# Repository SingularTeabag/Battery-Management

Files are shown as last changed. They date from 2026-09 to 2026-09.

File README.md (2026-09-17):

# **Battery-Management**
A repository to organize my battery management PCBs

## Single Cell 5 Volt Regulator
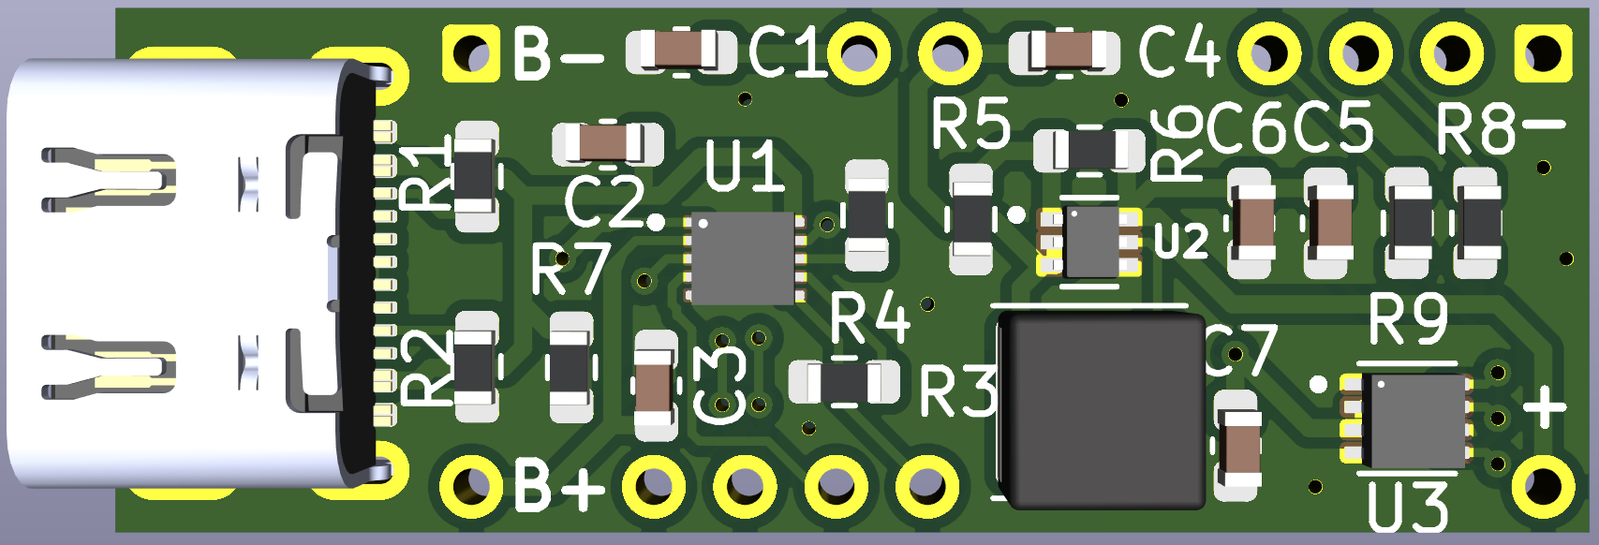
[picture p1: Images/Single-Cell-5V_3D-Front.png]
3D Front PCB Image

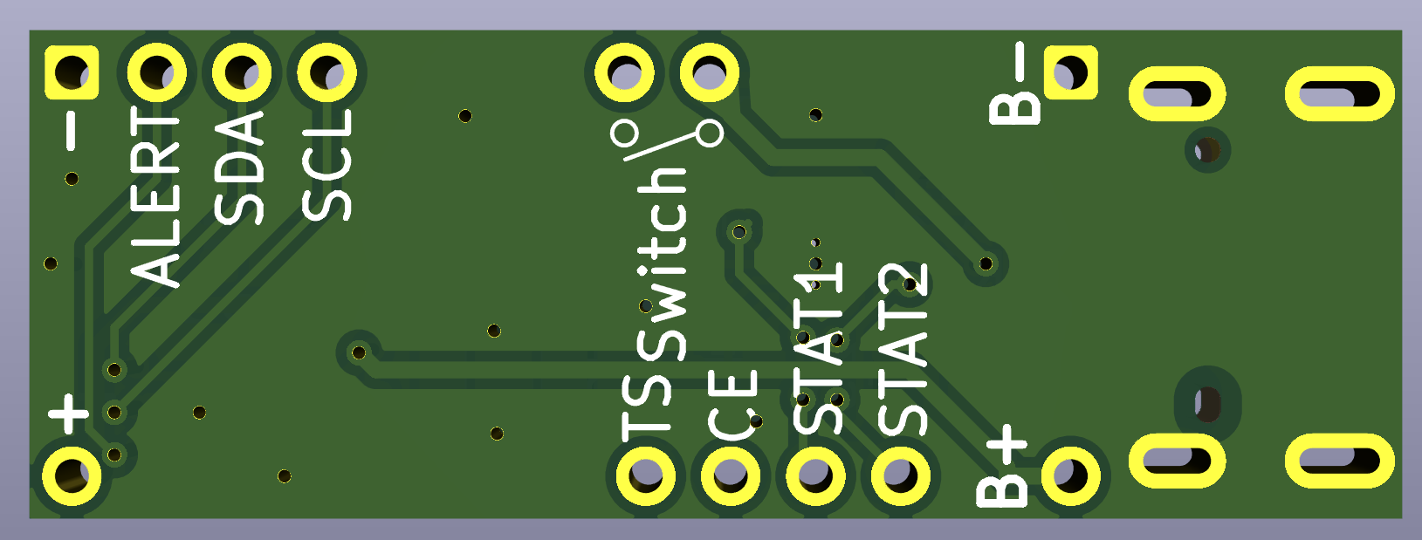
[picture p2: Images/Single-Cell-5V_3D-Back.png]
3D Back PCB Image

### Chips used
* [BQ25185DLHR](https://www.ti.com/product/BQ25185) - Battery Charging 
* [TPS61023DRLT](https://www.ti.com/product/TPS61023) - Voltage Regulation
* [MAX17048G](https://www.analog.com/en/products/max17048.html) - Fuel Gauge
### About 
This PCB is my first "real" PCB that I've designed from scratch using the datasheets of the three respective chips.
That aside this PCB is intended for easy battery support for prototyping with microcontroller development boards that require a stable 5 volt input. The board breaks out STAT1, STAT2, CE, and TS from BQ25185DLHR to allow data and control to the used microcontroller, and an external thermistor for battery safety. The board additionally has two pins meant to be used for an external on/off switch, marked on the back silkscreen. Like the battery charging IC the fuel gauges' data signals are also broken out to intended for use with the microcontroller. The USB type C port does not have it's data plus and data minus pins broken out, these are used as a differential pair which requires both wires to be exactly the same length and require impedance matching which all goes out the window when using external wires.

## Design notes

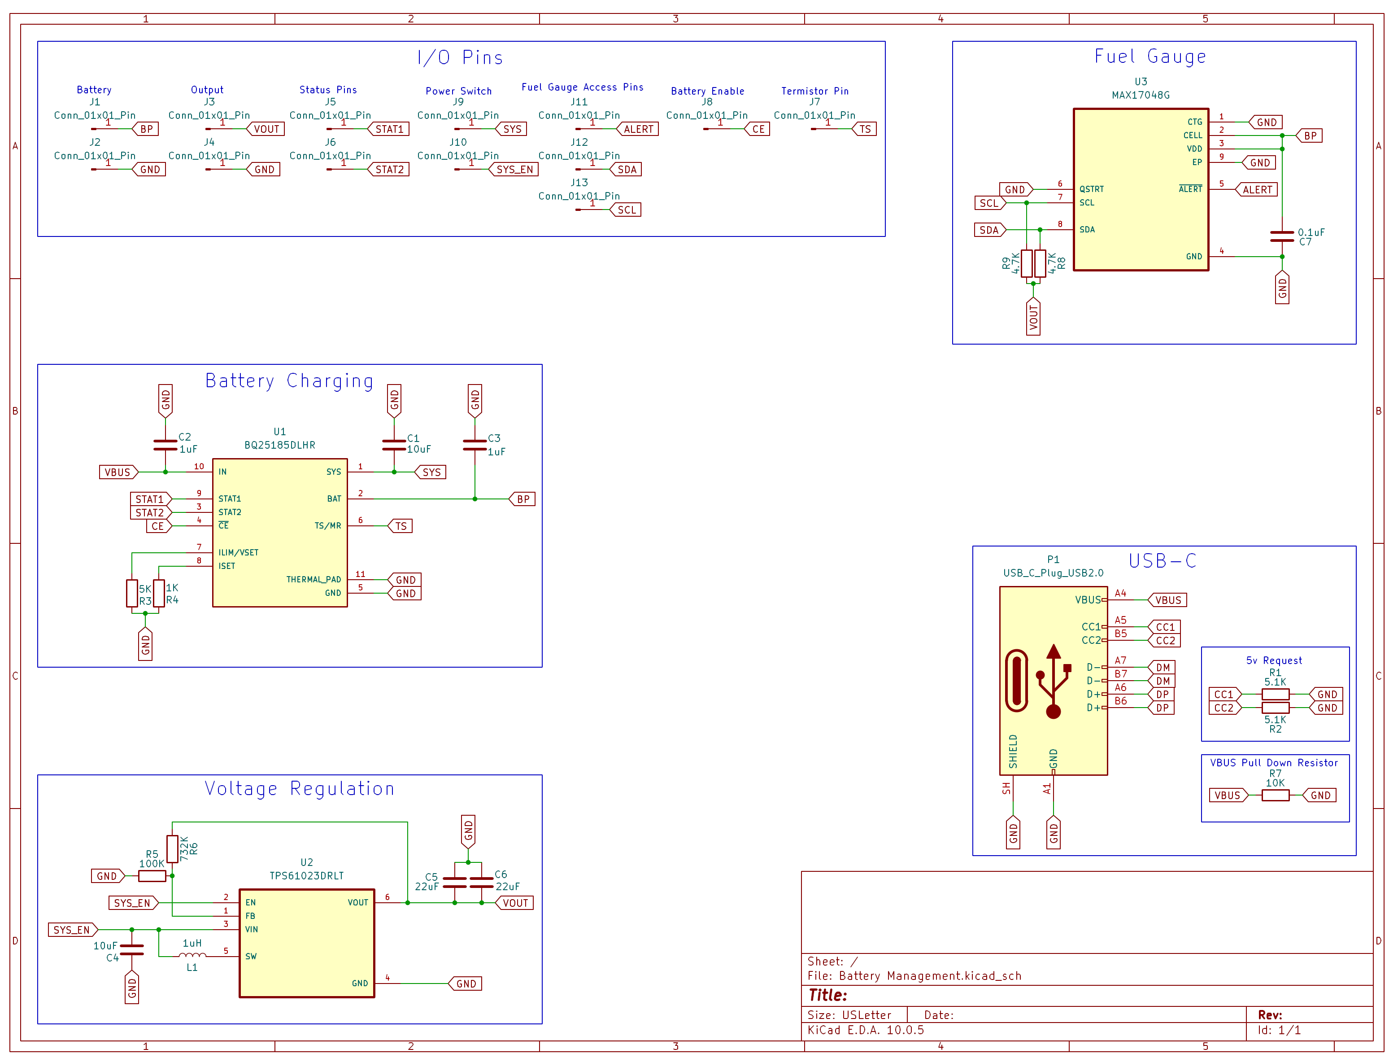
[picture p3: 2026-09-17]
Images/Single-Cell-5V_Schematic.png

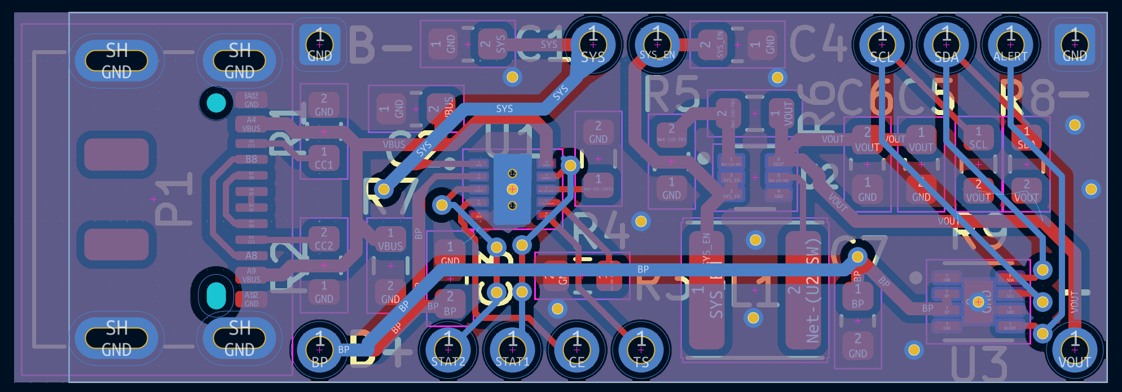
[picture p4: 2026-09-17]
Images/Single-Cell-5V_PCB-Back.png

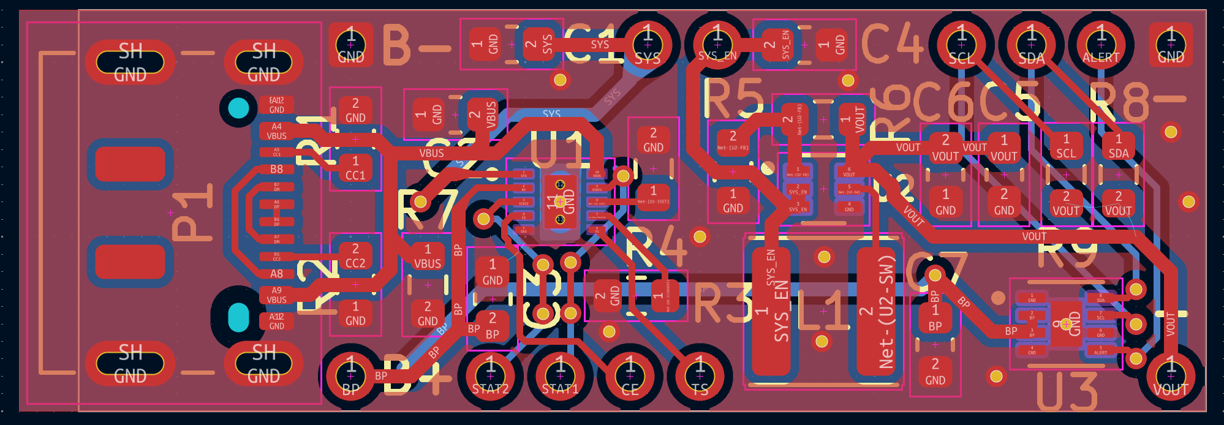
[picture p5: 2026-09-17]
Images/Single-Cell-5V_PCB-Front.png

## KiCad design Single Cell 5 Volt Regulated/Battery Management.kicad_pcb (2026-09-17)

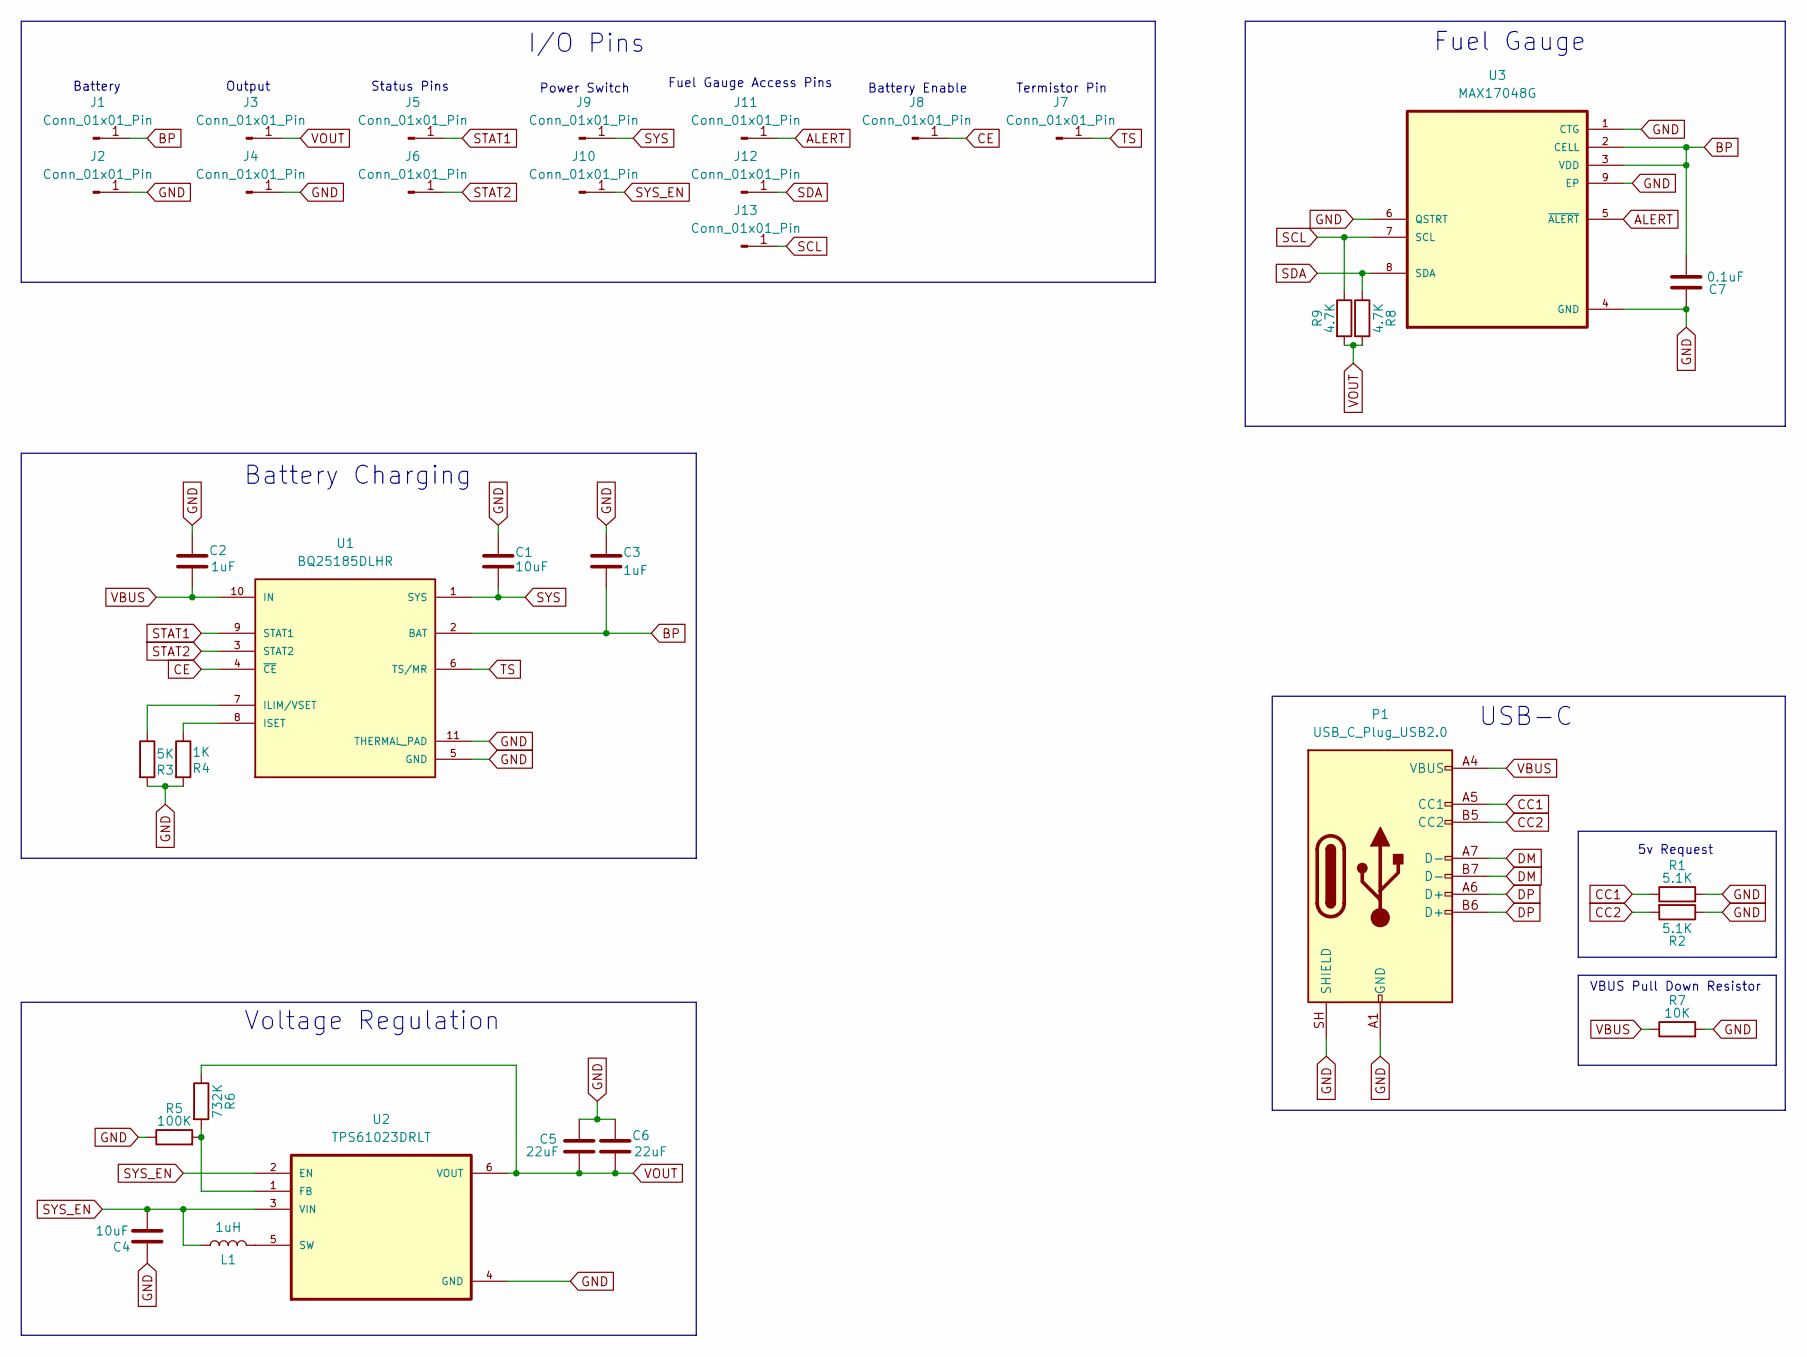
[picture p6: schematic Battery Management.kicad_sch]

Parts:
C1, C4: 10uF; C_0603_1608Metric
C2, C3: 1uF; C_0603_1608Metric
C5, C6: 22uF; C_0603_1608Metric
C7: 0.1uF; C_0603_1608Metric
J1, J3, J5, J6, J7, J8, J9, J10, J11, J12, J13: Conn_01x01_Pin; Connector Hole
J2, J4: Conn_01x01_Pin; Ground Hole
L1: 1uH; L_APV_ANR4030
P1: USB_C_Plug_USB2.0; USB_C_Receptacle_JAE_DX07S016JA1R1500
R1, R2: 5.1K; R_0603_1608Metric
R3: 5K; R_0603_1608Metric
R4: 1K; R_0603_1608Metric
R5: 100K; R_0603_1608Metric
R6: 732K; R_0603_1608Metric
R7: 10K; R_0603_1608Metric
R8, R9: 4.7K; R_0603_1608Metric
U1: BQ25185DLHR; IC_BQ25185DLHR; PARTREV OCTOBER 2023
U2: TPS61023DRLT; SOT50P160X60-6N
U3: MAX17048G; SON50P200X200X80-9N

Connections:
ALERT: J11.1 (Pin_1_1), U3.5 (~ALERT)
BP: C3.2, C7.1, J1.1 (Pin_1_1), U1.2 (BAT), U3.2 (CELL), U3.3 (VDD)
CC1: P1.A5 (CC1), R1.1
CC2: P1.B5 (CC2), R2.2
CE: J8.1 (Pin_1_1), U1.4 (~CE)
DM: P1.A7 (D-), P1.B7 (D-)
DP: P1.A6 (D+), P1.B6 (D+)
GND: C1.1, C2.1, C3.1, C4.1, C5.2, C6.1, C7.2, J2.1 (Pin_1_1), J4.1 (Pin_1_1), P1.A1 (GND), P1.A12 (GND), P1.B1 (GND), P1.B12 (GND), P1.SH (SHIELD), R1.2, R2.1, R3.2, R4.2, R5.1, R7.2, U1.5 (GND), U1.11 (THERMAL_PAD), U2.4 (GND), U3.1 (CTG), U3.4 (GND), U3.6 (QSTRT), U3.9 (EP)
unnamed: R3.1, U1.7 (ILIM/VSET)
unnamed: R4.1, U1.8 (ISET)
unnamed: R5.2, R6.2, U2.1 (FB)
unnamed: L1.2, U2.5 (SW)
SCL: J13.1 (Pin_1_1), R9.1, U3.7 (SCL)
SDA: J12.1 (Pin_1_1), R8.1, U3.8 (SDA)
STAT1: J5.1 (Pin_1_1), U1.9 (STAT1)
STAT2: J6.1 (Pin_1_1), U1.3 (STAT2)
SYS: C1.2, J9.1 (Pin_1_1), U1.1 (SYS)
SYS_EN: C4.2, J10.1 (Pin_1_1), L1.1, U2.2 (EN), U2.3 (VIN)
TS: J7.1 (Pin_1_1), U1.6 (TS/MR)
VBUS: C2.2, P1.A4 (VBUS), P1.A9 (VBUS), P1.B4 (VBUS), P1.B9 (VBUS), R7.1, U1.10 (IN)
VOUT: C5.1, C6.2, J3.1 (Pin_1_1), R6.1, R8.2, R9.2, U2.6 (VOUT)

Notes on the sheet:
Fuel Gauge
Battery Enable
Battery
Status Pins
Output
Voltage Regulation
Battery Charging
USB-C
5v Request
I/O Pins
Fuel Gauge Access Pins
Termistor Pin
VBUS Pull Down Resistor
Power Switch

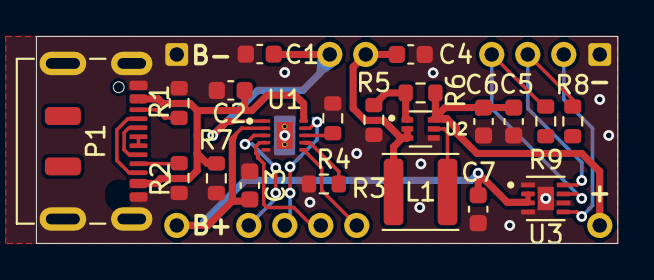
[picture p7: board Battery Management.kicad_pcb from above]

Board: 2 copper layers, 32.3 x 11.5 mm, 34 parts (0 on the bottom side), 21 nets.

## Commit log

2026-09-17 Edited PCB
    Added in via stitching between top and bottom ground layers and vias connecting thermal pads to the bottom ground plane for better thermal distribution
    [Battery Management.kicad_pcb]
2026-09-17 Edit PCB
2026-09-17 Added Single Cell 5V Rev. 3
2026-09-17 Rename Schematic.png to Single Cell 5V_Schematic.png
2026-09-17 Removed Tracking for 'Battery Management'
    These files are the same as 'Single Cell 5V Regulated' just named differently locally. I'm using git for the first time
    [Battery Management.kicad_pcb, Battery Management.kicad_sch]
2026-09-17 Removed KiCad ~ files
2026-09-17 Updated KiCad Files
    [Battery Management.kicad_pcb]
